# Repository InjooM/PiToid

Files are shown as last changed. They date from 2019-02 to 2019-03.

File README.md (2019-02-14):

# PiToid

## Intro
Small beginner's electronics project with Raspberry Pi Zero

This is a small project I started about mid-way through my first semester as a freshman at the University of Georgia. It is a Raspberry Pi in an Altoids Tin that acts as an emulator for video games through Retropie. In order to have a functioning "gameboy" I needed several components:

- A display
- An audio system
- A power management system
- Controls

## Display
For the display, I am using a 1.8" TFT display sold from Adafruit that came with a display driver. It uses SPI to communicate with the Raspberry Pi, so I designed a compact breakout board, referenced from the Adafruit breakout board, that fit my Altoids tin and used an FPC connector.

## Audio
For audio, I configured some of the GPIO pins of the RPi to output audio through PWM, ran it though a low-pass filter, then into an LM4810 audio amp with a 2-gang potentiometer acting as the feedback resistors for the amp. The output is a switching 3.5mm audio jack that runs into 2 8 Ohm speakers. This way I can plug in headphones as well.

## Power
For power management I am using a 3.7V Li-Poly battery sold by Adafruit, and I designed a battery charger and step-up, referenced from the Adafruit PowerBoost 1000 Charger. It also has load-sharing capabilites so when plugged in, the battery will only be charging.

## Controls
For controls I designed a breakout board for the Raspberry Pi and soldered tactile switches onto it, which are connected to the GPIO pins. The Pi is running Adafruit's Retrogame, which configures some GPIO pins as keyboard inputs.

## Final Words
The purpose of this project was not simply to build a DIY gameboy, although I do find gameboys to be fun. I mainly wanted to do this project because I wanted more hands-on experience designing and manufacturing PCB's, as well as putting my circuit analysis skills to the test. Reverse engineering the schematics from Adafruit and reading the datasheets for all the complicated components was difficult, however I believe it helped greatly in developing my electronics design skills. I plan on using these skills in the future for other applications, such as specific instrumentation design.

Most, if not all, of my boards are designed through EAGLE, and fabricated through OshPark. I ordered all my components from Digi-key or Mouser.

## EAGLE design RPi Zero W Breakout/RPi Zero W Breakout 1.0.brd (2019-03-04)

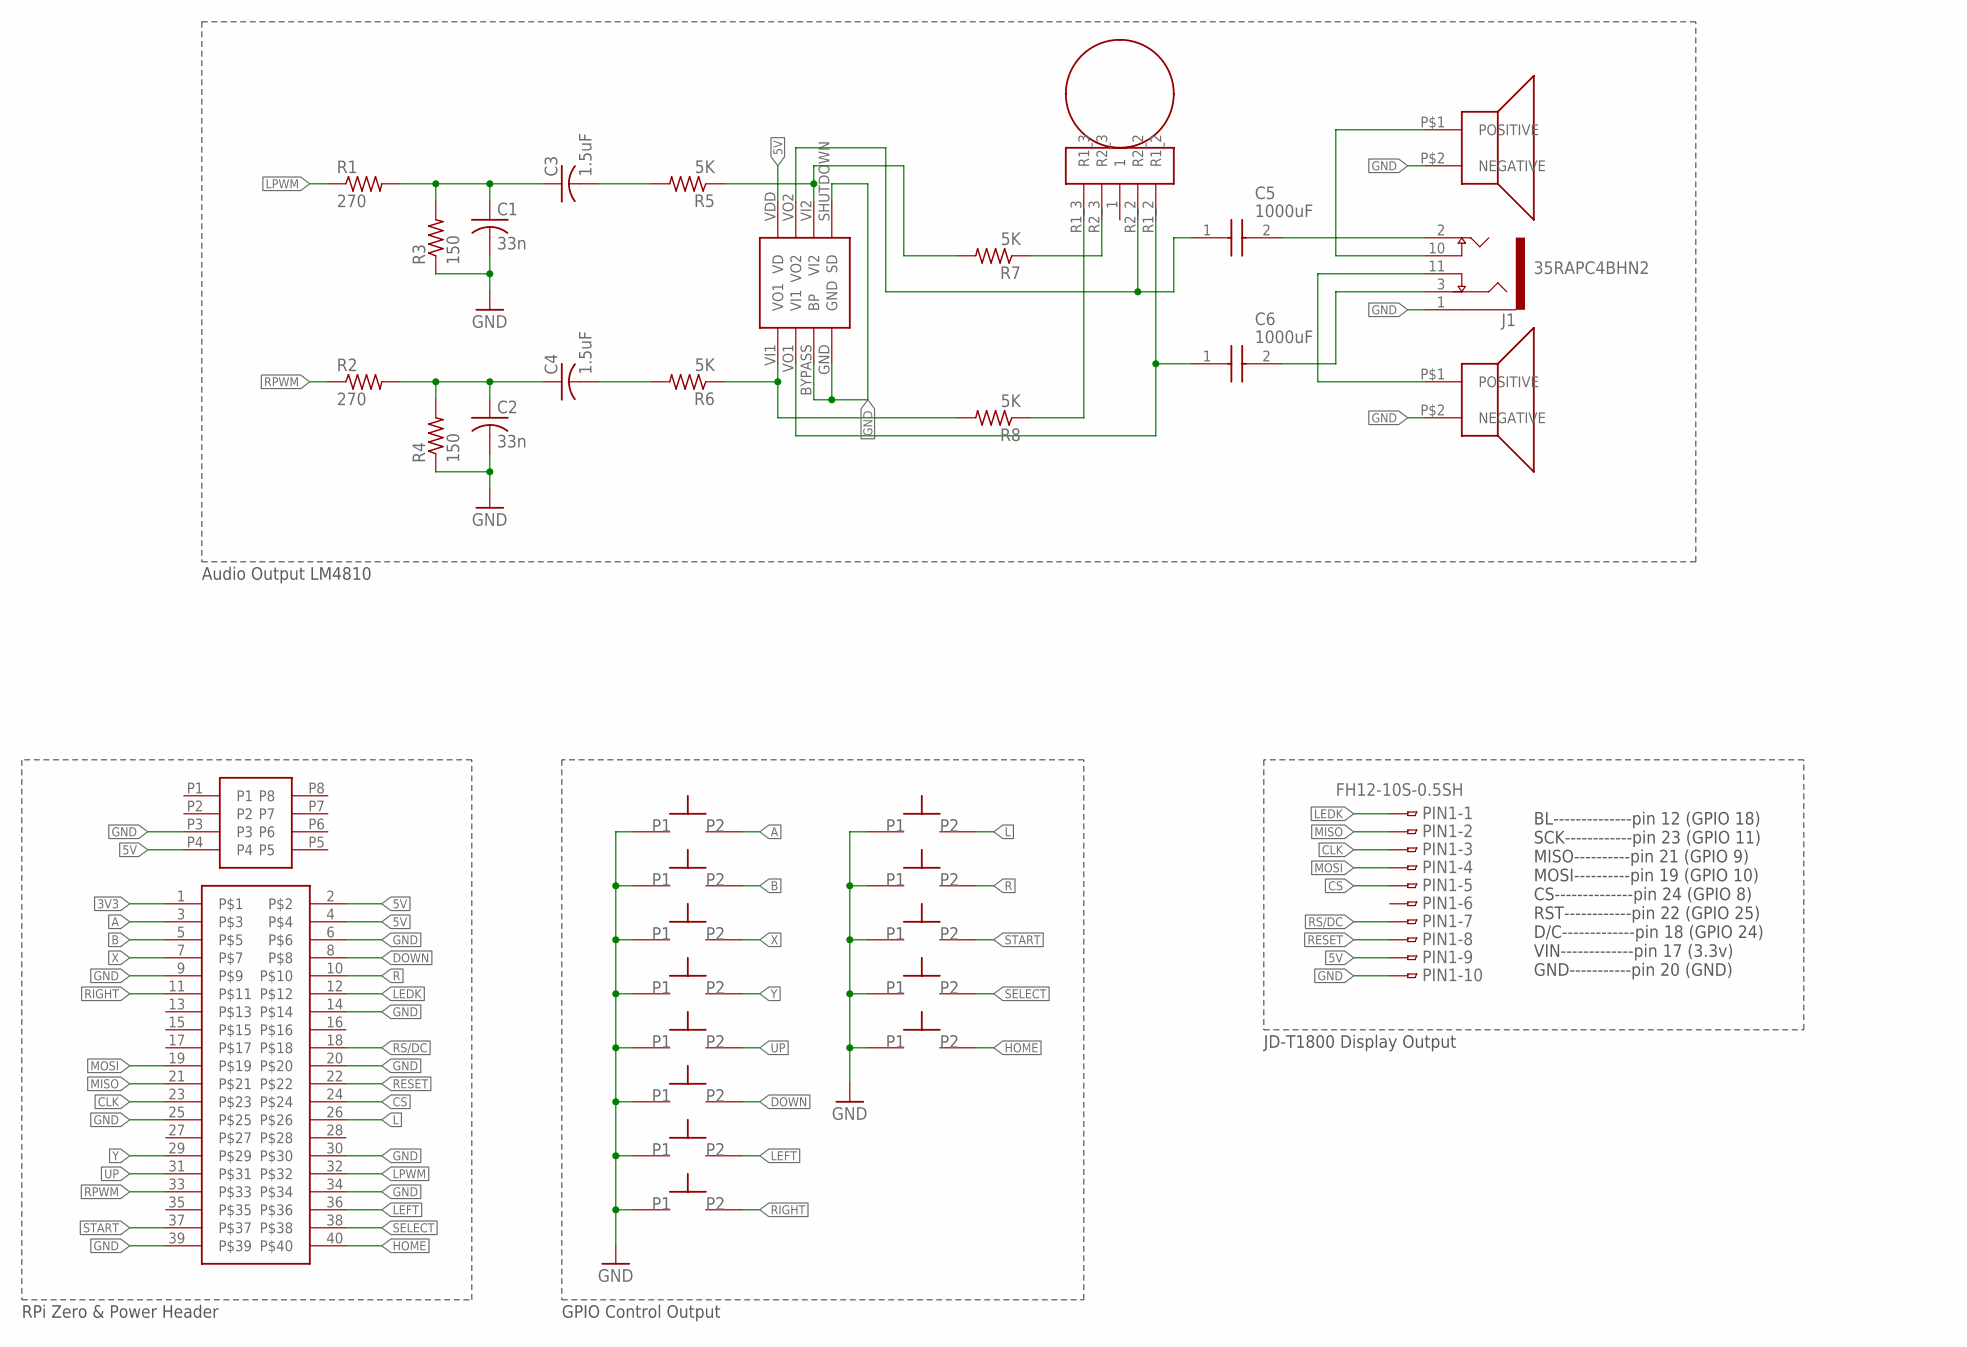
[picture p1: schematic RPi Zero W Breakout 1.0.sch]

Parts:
A: SPST_TACTILE_SWITCH; SPST_TACTILESWITCH_TL3301PF160QG
B: SPST_TACTILESWITCH_TL3301PF160QG
C1, C2: 33n; C0805K
C3, C4: 1.5uF; C0805K
C5, C6: 1000uF; UWT(8X10)
DOWN: SPST_TACTILESWITCH_TL3301PF160QG
HOME: SPST_TACTILESWITCH_TL3301PF160QG
J1: 35RAPC4BHN2; SWITCHCRAFT_35RAPC4BHN2
LEFT: SPST_TACTILESWITCH_TL3301PF160QG
LSPK: SP-1208
PIN1: FH12-10S-0.5SH
R1, R2: 270; R0805
R3, R4: 150; R0805
R5, R6, R7, R8: 5K; R0805
RF: RK14J12A0A0K
RIGHT: SPST_TACTILESWITCH_TL3301PF160QG
RSPK: SP-1208
SELECT: SPST_TACTILESWITCH_TL3301PF160QG
START: SPST_TACTILE_SWITCH; SPST_TACTILESWITCH_TL3301PF160QG
U$1: RPI_ZERO
U$2: LM4810MM/NOPBCT-ND; NOPBCT-ND
U$3: M22-6340442
U$4, U$5: SPST_TACTILE_SWITCHRIGHTANGLEBENT; SPST_TACTILESWITCH_TL3360CF185Q_BENTFRAME
UP: SPST_TACTILESWITCH_TL3301PF160QG
X: SPST_TACTILESWITCH_TL3301PF160QG
Y: SPST_TACTILESWITCH_TL3301PF160QG

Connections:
3V3: U$1.1
5V: PIN1.9, U$1.2, U$1.4, U$2.VDD (VD), U$3.P4
A: A.P$3, U$1.3
B: B.P$3, U$1.5
CLK: PIN1.3, U$1.23
CS: PIN1.5, U$1.24
DOWN: DOWN.P$3, U$1.8
GND: A.P$1, B.P$1, C1.2, C2.2, DOWN.P$1, HOME.P$1, J1.1, LEFT.P$1, LSPK.P$2 (NEGATIVE), PIN1.10, R3.1, R4.1, RIGHT.P$1, RSPK.P$2 (NEGATIVE), SELECT.P$1, START.P$1, U$1.6, U$1.9, U$1.14, U$1.20, U$1.25, U$1.30, U$1.34, U$1.39, U$2.BYPASS (BP), U$2.GND, U$2.SHUTDOWN (SD), U$3.P3, U$4.P$1, U$5.P$1, UP.P$1, X.P$1, Y.P$1
HOME: HOME.P$3, U$1.40
L: U$1.26, U$4.P$2
LEDK: PIN1.1, U$1.12
LEFT: LEFT.P$3, U$1.36
LPWM: R1.1, U$1.32
MISO: PIN1.2, U$1.21
MOSI: PIN1.4, U$1.19
unnamed: C1.1, C3.1, R1.2, R3.2
unnamed: C2.1, C4.1, R2.2, R4.2
unnamed: C3.2, R5.2
unnamed: R7.1, RF.R2_3
unnamed: C4.2, R6.2
unnamed: R8.1, RF.R1_3
unnamed: C6.1 (+), RF.R1_2, U$2.VO1 (VI1)
unnamed: C5.1 (+), RF.R2_2, U$2.VO2
unnamed: C5.2 (-), J1.2
unnamed: C6.2 (-), J1.3
unnamed: J1.10, LSPK.P$1 (POSITIVE)
unnamed: J1.11, RSPK.P$1 (POSITIVE)
unnamed: R5.1, R7.2, U$2.VI2
unnamed: R6.1, R8.2, U$2.VI1 (VO1)
R: U$1.10, U$5.P$2
RESET: PIN1.8, U$1.22
RIGHT: RIGHT.P$3, U$1.11
RPWM: R2.1, U$1.33
RS/DC: PIN1.7, U$1.18
SELECT: SELECT.P$3, U$1.38
START: START.P$3, U$1.37
UP: U$1.31, UP.P$3
X: U$1.7, X.P$3
Y: U$1.29, Y.P$3

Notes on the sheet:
BL--------------pin 12 (GPIO 18) SCK------------pin 23 (GPIO 11) MISO----------pin 21 (GPIO 9) MOSI----------pin 19 (GPIO 10) CS--------------pin 24 (GPIO 8) RST------------pin 22 (GPIO 25) D/C-------------pin 18 (GPIO 24) VIN-------------pin 17 (3.3v) GND-----------pin 20 (GND)
RPi Zero & Power Header
GPIO Control Output
JD-T1800 Display Output
Audio Output LM4810

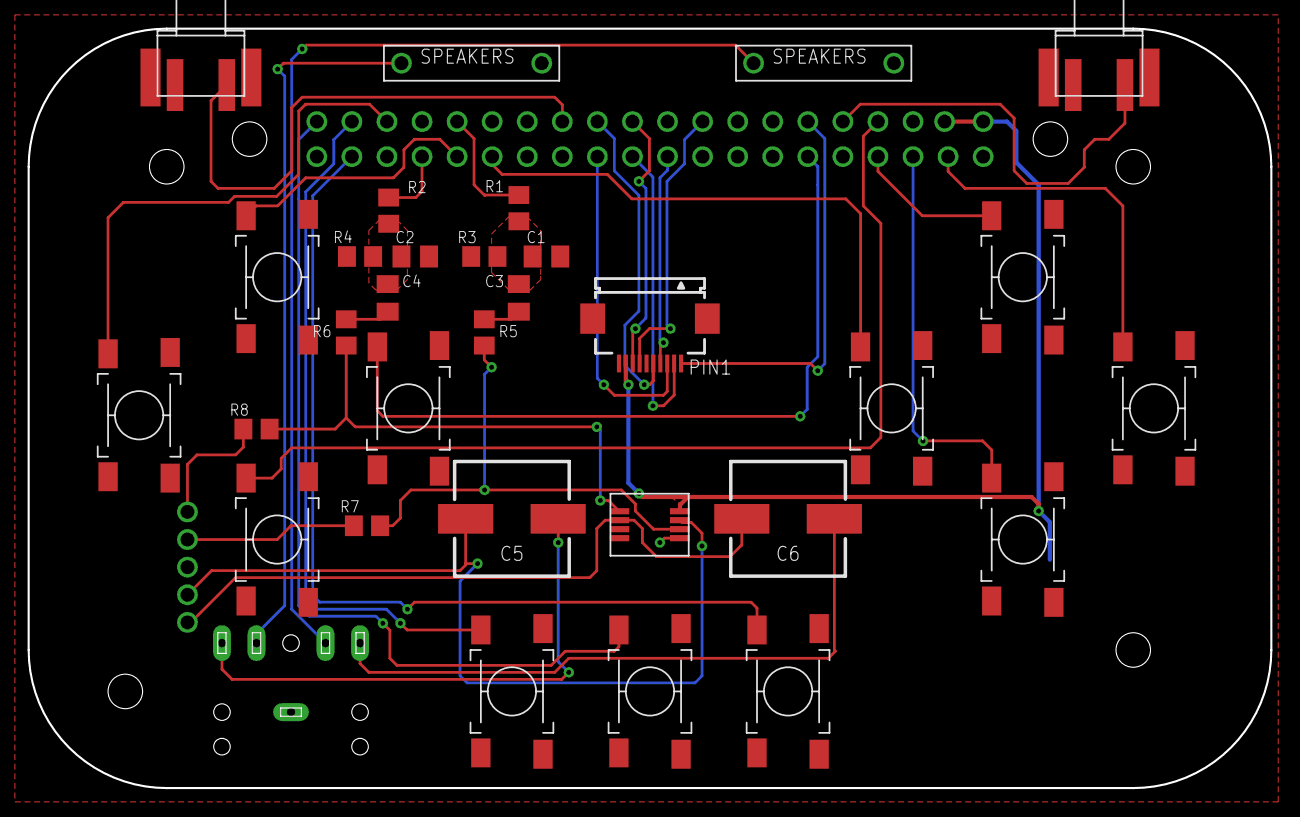
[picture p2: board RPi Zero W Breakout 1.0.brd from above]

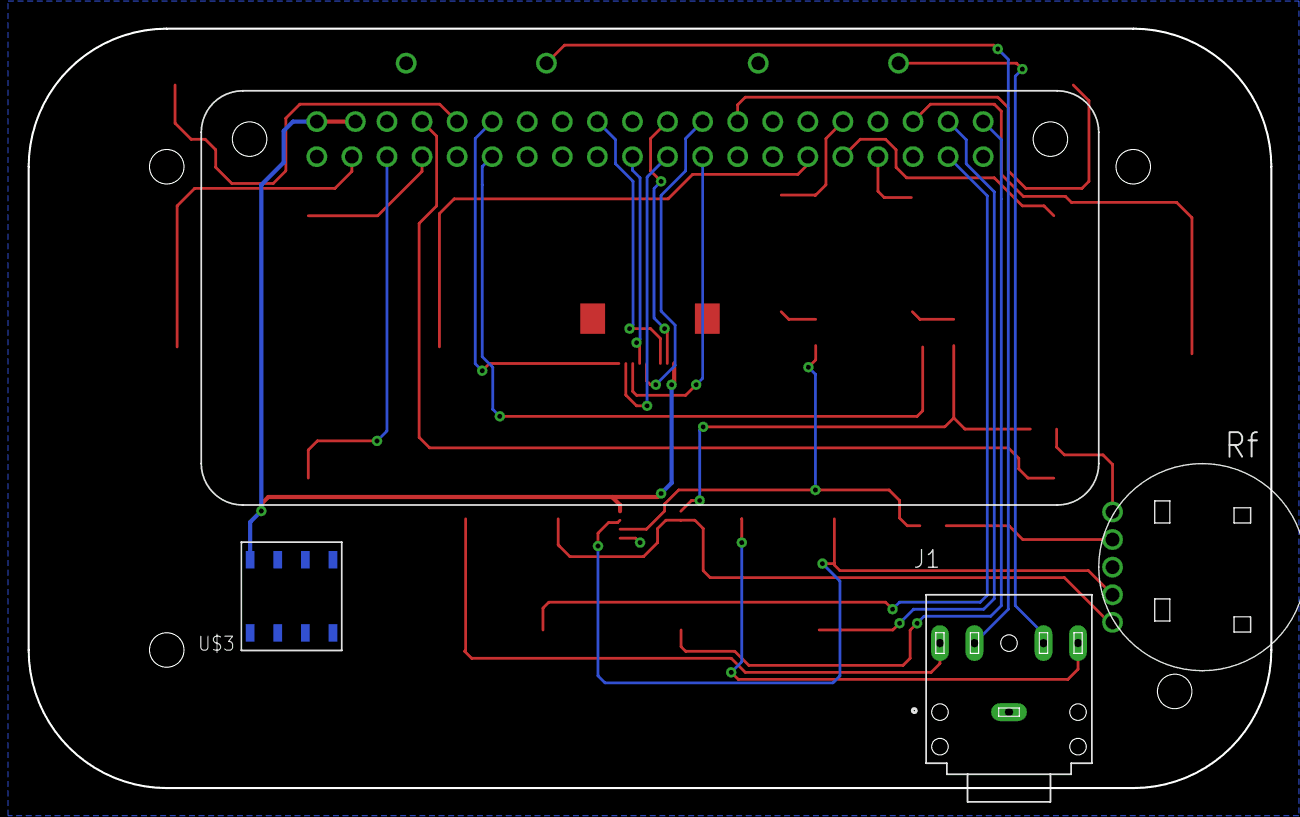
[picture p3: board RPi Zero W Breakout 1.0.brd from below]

Board: 2 copper layers, 90.0 x 55.0 mm, 35 parts (4 on the bottom side), 38 nets.

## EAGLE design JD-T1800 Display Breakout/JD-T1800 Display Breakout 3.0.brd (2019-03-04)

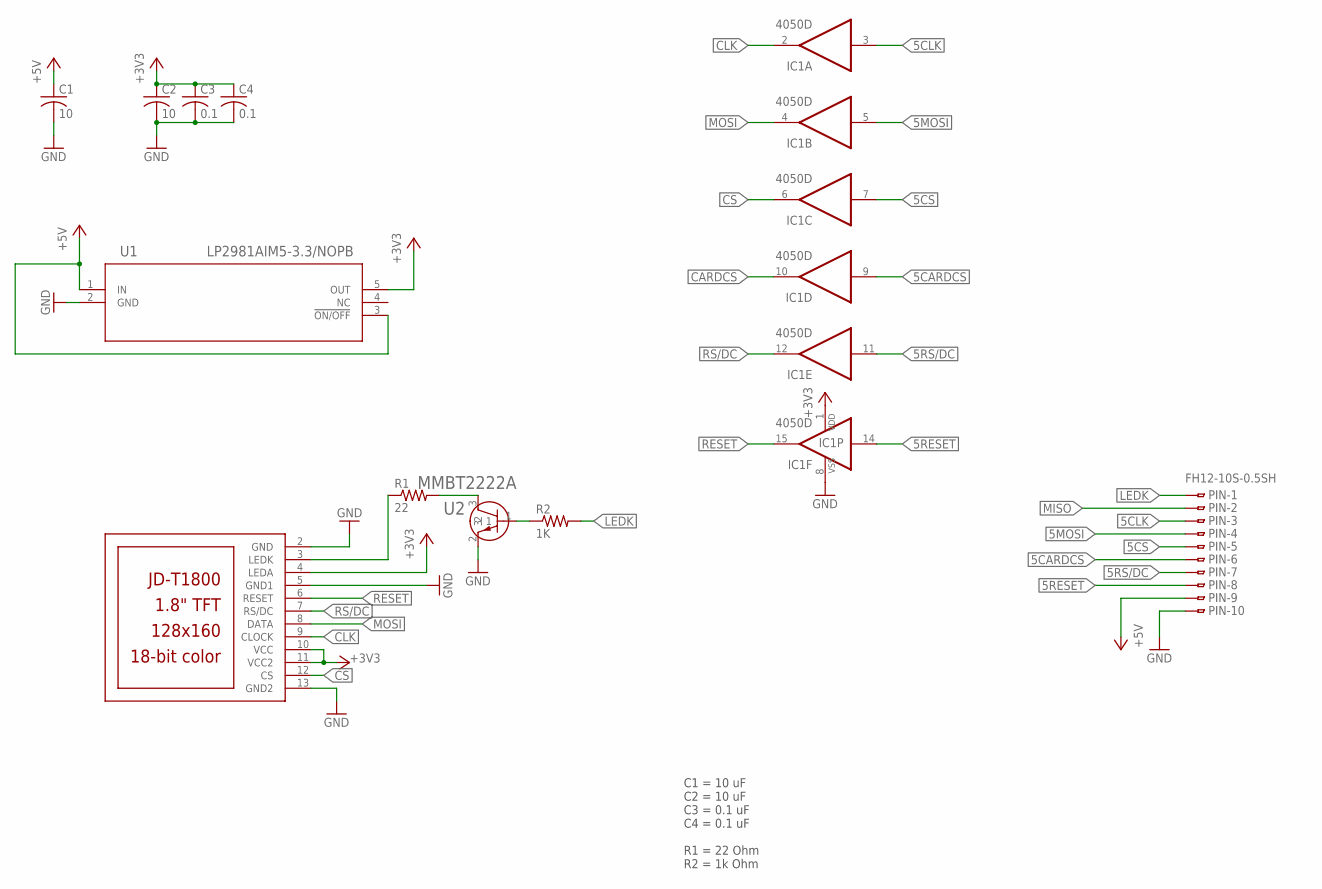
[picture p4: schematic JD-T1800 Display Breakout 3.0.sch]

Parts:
C1, C2: 10; C0805
C3, C4: 0.1; C0805
IC1: 4050D; SO16
PIN: FH12-10S-0.5SH
R1: 22; R0805
R2: 1K; R0805
U1: LP2981AIM5-3.3/NOPB; MF05A
U2: MMBT2222A; SOT23
U$1: JD-T1800

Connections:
5CARDCS: IC1.9 (I), PIN.6
5CLK: IC1.3 (I), PIN.3
5CS: IC1.7 (I), PIN.5
5MOSI: IC1.5 (I), PIN.4
5RESET: IC1.14 (I), PIN.8
5RS/DC: IC1.11 (I), PIN.7
+3V3: C2.1, C3.1, C4.1, IC1.1 (VDD), U1.5 (OUT), U$1.4 (LEDA), U$1.10 (VCC), U$1.11 (VCC2)
+5V: C1.1, PIN.9, U1.1 (IN), U1.3 (!ON/OFF)
CARDCS: IC1.10 (O)
CLK: IC1.2 (O), U$1.9 (CLOCK)
CS: IC1.6 (O), U$1.12 (CS)
GND: C1.2, C2.2, C3.2, C4.2, IC1.8 (VSS), PIN.10, U1.2 (GND), U2.2, U$1.2 (GND), U$1.5 (GND1), U$1.13 (GND2)
LEDK: PIN.1, R2.2
MISO: PIN.2
MOSI: IC1.4 (O), U$1.8 (DATA)
unnamed: R1.1, U$1.3 (LEDK)
unnamed: R1.2, U2.3
unnamed: R2.1, U2.1
RESET: IC1.15 (O), U$1.6 (RESET)
RS/DC: IC1.12 (O), U$1.7 (RS/DC)

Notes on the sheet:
C1 = 10 uF C2 = 10 uF C3 = 0.1 uF C4 = 0.1 uF R1 = 22 Ohm R2 = 1k Ohm

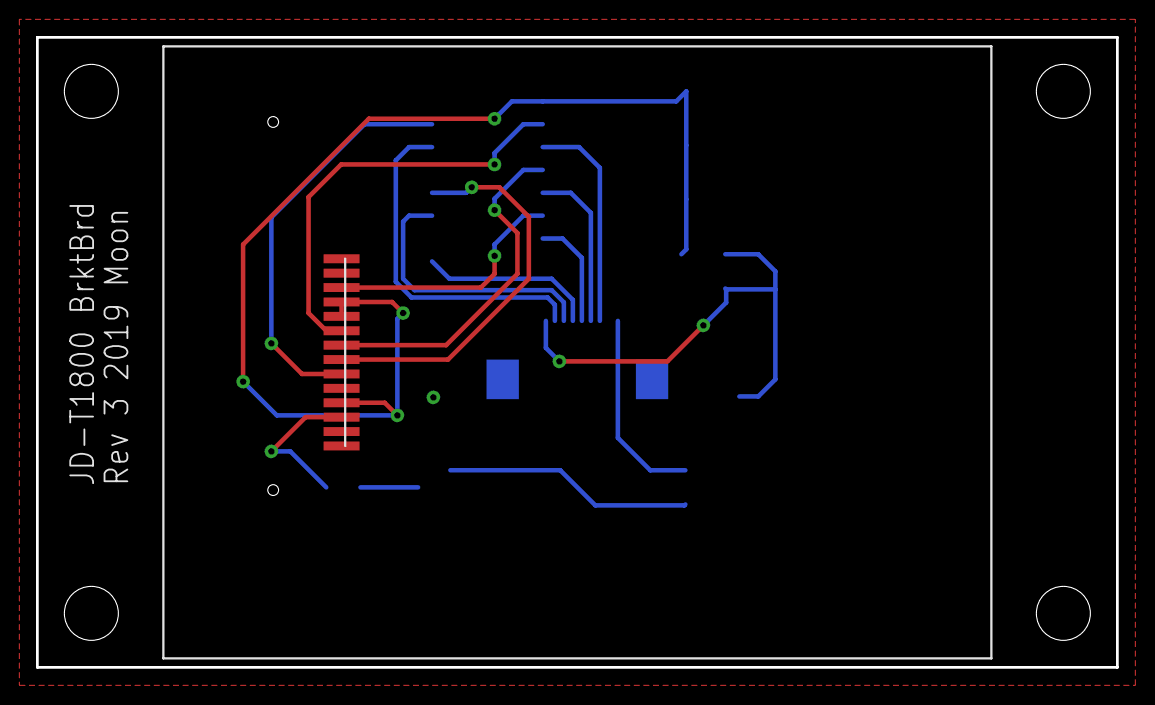
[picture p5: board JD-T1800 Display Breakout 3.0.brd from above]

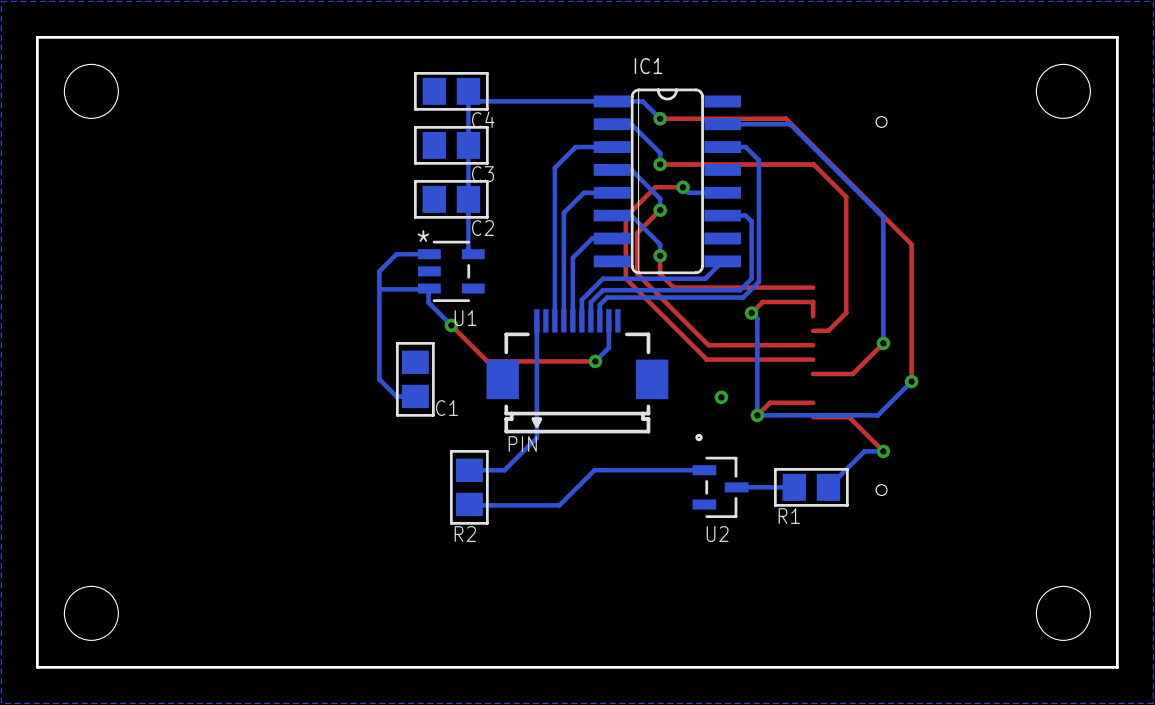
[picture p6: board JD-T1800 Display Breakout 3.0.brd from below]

Board: 2 copper layers, 60.0 x 35.0 mm, 11 parts (10 on the bottom side), 18 nets.

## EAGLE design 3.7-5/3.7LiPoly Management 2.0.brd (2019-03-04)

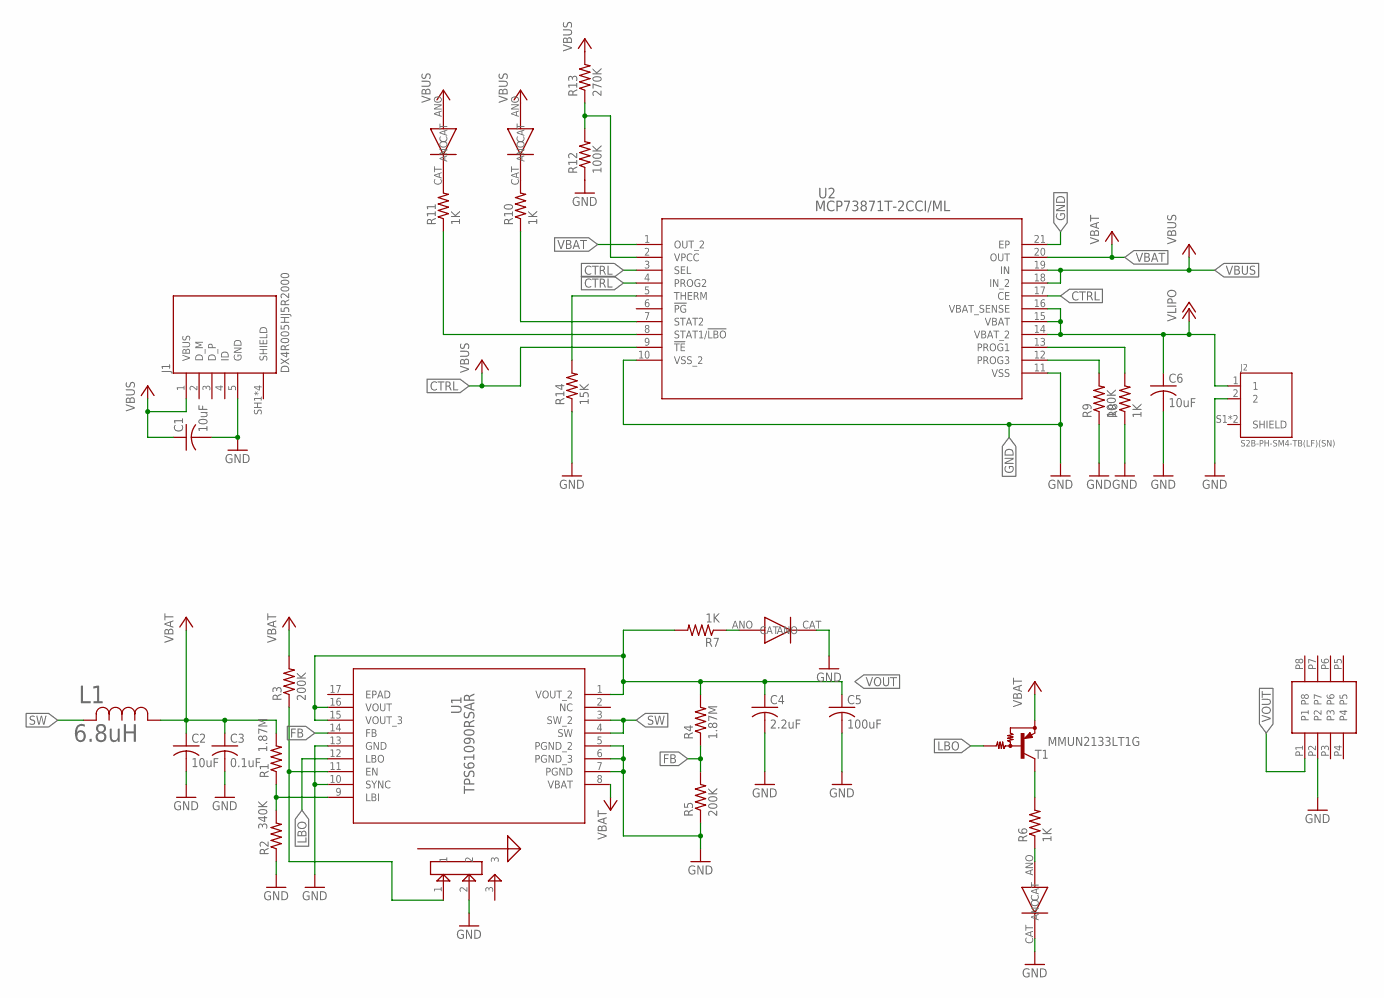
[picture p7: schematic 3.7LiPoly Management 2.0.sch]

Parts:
C1, C2, C6: 10uF; C0805
C3: 0.1uF; C0805
C4: 2.2uF; C0805
C5: 100uF; C0805
CHARGE: YELLOW; WP934AD
DONE: GREEN; WP934AD
H1: M22-6340442
J1: DX4R005HJ5R2000; JAE_DX4R005HJ5R2000
J2: S2B-PH-SM4-TB(LF)(SN); JST_S2B-PH-SM4-TB(LF)(SN)
L1: 6.8uH; IND_5028
LBO: RED; WP934AD
POWERON: BLUE; WP934EW
R1, R4: 1.87M; R0805
R2: 340K; R0805
R3, R5: 200K; R0805
R6, R7, R8, R10, R11: 1K; R0805
R9, R12: 100K; R0805
R13: 270K; R0805
R14: 15K; R0805
T1: MMUN2133LT1G; SC59-BEC
U1: TPS61090RSAR; RSA16_2P7X2P7
U2: MCP73871T-2CCI/ML; QFN20_4X4MC
U$2: JS102011SAQN

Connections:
+3V3: CHARGE.ANO, DONE.ANO, R13.2
CTRL: U2.3 (SEL), U2.4 (PROG2), U2.9 (!TE), U2.17 (CE)
FB: R4.1, R5.2, U1.14 (FB)
GND: C1.2, C2.2, C3.2, C4.2, C5.2, C6.2, H1.P2, J1.5 (GND), J2.2, LBO.CAT, POWERON.CAT, R2.1, R5.1, R8.1, R9.1, R12.1, R14.1, U1.5 (PGND_2), U1.6 (PGND_3), U1.7 (PGND), U1.10 (SYNC), U1.13 (GND), U2.10 (VSS_2), U2.11 (VSS), U2.21 (EP), U$2.2
LBO: T1.B, U1.12 (LBO)
unnamed: R1.1, R2.2, U1.9 (LBI)
unnamed: R3.1, U1.11 (EN), U$2.1
unnamed: CHARGE.CAT, R11.2
unnamed: R8.2, U2.13 (PROG1)
unnamed: R6.2, T1.C
unnamed: LBO.ANO, R6.1
unnamed: POWERON.ANO, R7.1
unnamed: R9.2, U2.12 (PROG3)
unnamed: DONE.CAT, R10.2
unnamed: R11.1, U2.8 (STAT1/!LBO)
unnamed: R10.1, U2.7 (STAT2)
unnamed: R14.2, U2.5 (THERM)
unnamed: R12.2, R13.1, U2.2 (VPCC)
SW: L1.2, U1.3 (SW_2), U1.4 (SW)
VBAT: C2.1, C3.1, L1.1, R1.2, R3.2, T1.E, U1.8 (VBAT), U2.1 (OUT_2), U2.20 (OUT)
VBUS: C1.1, J1.1 (VBUS), U2.18 (IN_2), U2.19 (IN)
VLIPO: C6.1, J2.1, U2.14 (VBAT_2), U2.15 (VBAT), U2.16 (VBAT_SENSE)
VOUT: C4.1, C5.1, H1.P1, R4.2, R7.2, U1.1 (VOUT_2), U1.15 (VOUT_3), U1.16 (VOUT)

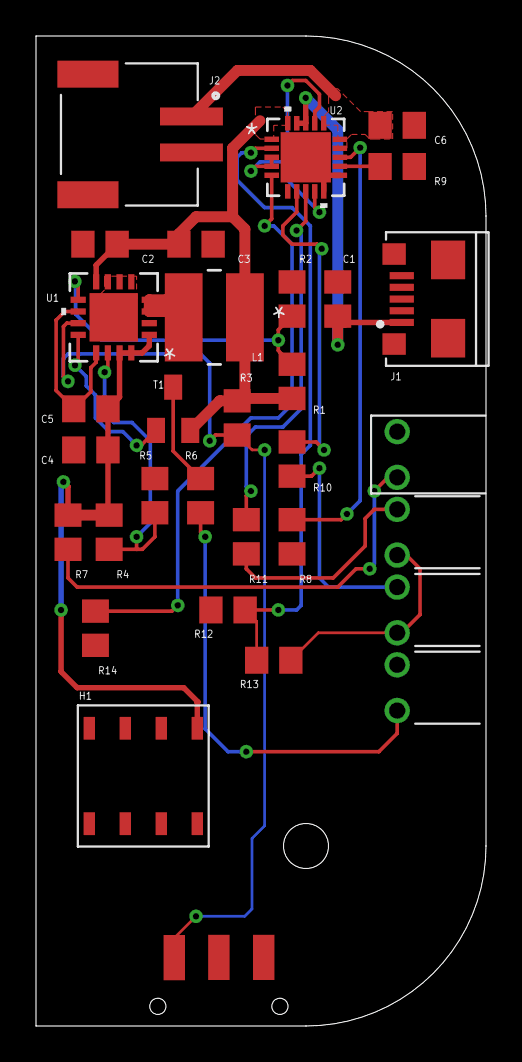
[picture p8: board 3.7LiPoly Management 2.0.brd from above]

Board: 2 copper layers, 25.0 x 55.0 mm, 32 parts (0 on the bottom side), 23 nets.

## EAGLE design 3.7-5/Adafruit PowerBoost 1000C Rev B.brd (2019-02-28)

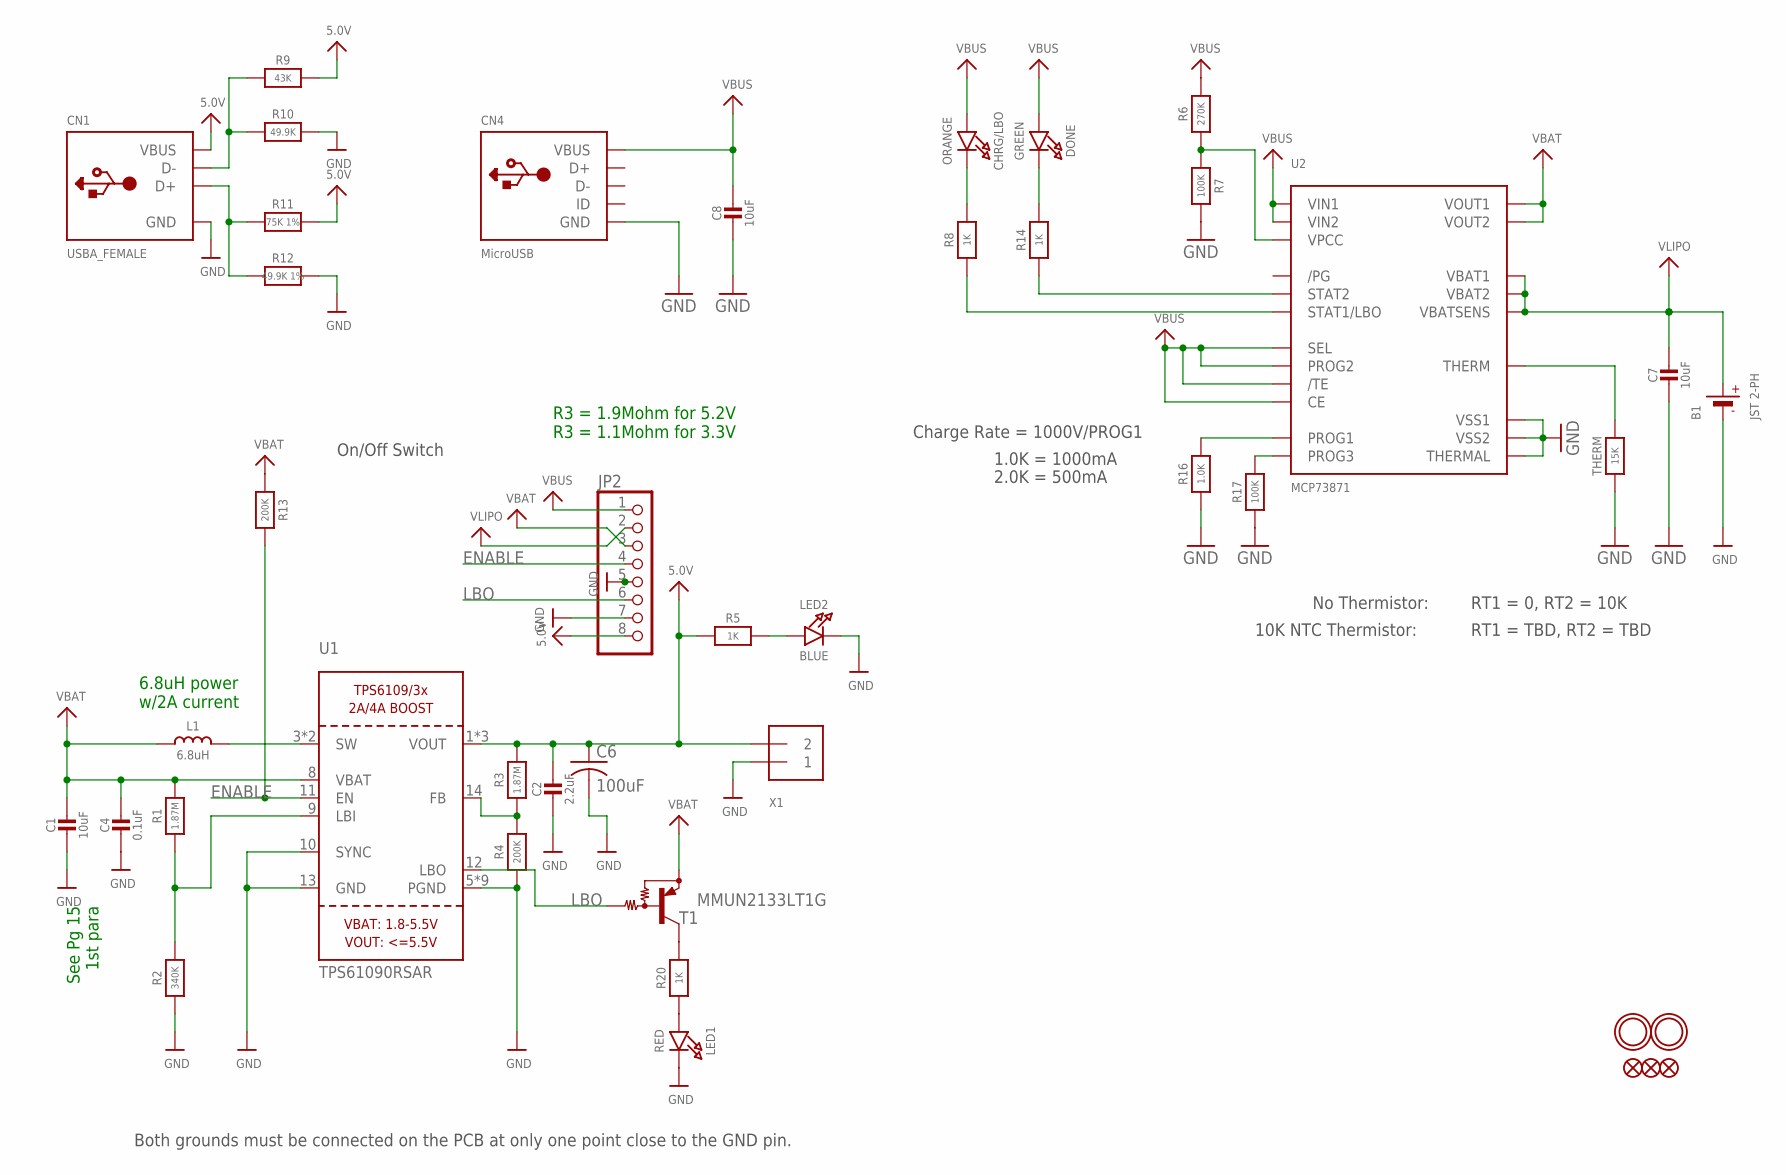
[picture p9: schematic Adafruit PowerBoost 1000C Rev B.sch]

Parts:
B1: JST 2-PH; JSTPH2
C1, C7, C8: 10uF; 0805-NO
C2: 2.2uF; 0805-NO
C4: 0.1uF; 0805_10MGAP
C6: 100uF; C1210
CHRG/LBO: ORANGE; CHIPLED_0805_NOOUTLINE
CN1: USBA_FEMALE; USB_HOST-PTH
CN4: MicroUSB; 4UCONN_20329
DONE: GREEN; CHIPLED_0805_NOOUTLINE
FID1, FID2, FID3: FIDUCIAL""; FIDUCIAL_1MM
JP2: HEADER-1X8ROUND; 1X08_ROUND
L1: 6.8uH; INDUCTOR_5X5MM_TDK_VLC5045
LED1: RED; CHIPLED_0805_NOOUTLINE
LED2: BLUE; CHIPLED_0805_NOOUTLINE
R1: 1.87M; _0805MP
R2: 340K; _0805MP
R3: 1.87M; 0805-NO
R4, R13: 200K; 0805-NO
R5, R8, R14, R20: 1K; 0805-NO
R6: 270K; 0805-NO
R7, R17: 100K; 0805-NO
R9: 43K; 0805-NO
R10: 49.9K; 0805-NO
R11: 75K 1%; 0805-NO
R12: 49.9K 1%; 0805-NO
R16: 1.0K; 0805-NO
T1: MMUN2133LT1G; SC59-BEC
THERM: 15K; 0805-NO
U1: TPS61090RSAR; PVQFN-16
U2: MCP73871; QFN20_4MM
U$10, U$11: MOUNTINGHOLE2.5; MOUNTINGHOLE_2.5_PLATED
X1: TERMBLOCK_1X2; TERMBLOCK_1X2-3.5MM

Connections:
5.0V: C2.1, C6.1, CN1.VBUS, JP2.8, R3.2, R5.1, R9.2, R11.2, U1.1 (VOUT), U1.15 (VOUT), U1.16 (VOUT), X1.2
D+: CN1.D+, R11.1, R12.1
D-: CN1.D-, R9.1, R10.1
ENABLE: JP2.4, R13.2, U1.11 (EN)
GND: B1.1 (-), C1.2, C2.2, C4.2, C6.2, C7.2, C8.2, CN1.GND, CN4.BASE@1 (GND), CN4.BASE@2 (GND), CN4.GND, CN4.SPRT@1 (GND), CN4.SPRT@2 (GND), CN4.SPRT@3 (GND), CN4.SPRT@4 (GND), JP2.5, JP2.7, LED1.C, LED2.C, R2.1, R4.1, R7.2, R10.2, R12.2, R16.1, R17.1, THERM.1, U1.5 (PGND), U1.6 (PGND), U1.7 (PGND), U1.10 (SYNC), U1.13 (GND), U1.P$18 (PGND), U1.P$19 (PGND), U1.P$20 (PGND), U1.P$21 (PGND), U1.P$22 (PGND), U1.THERMAL (PGND), U2.P$10 (VSS1), U2.P$11 (VSS2), U2.P$21 (THERMAL), X1.1
LBO: JP2.6, T1.B, U1.12 (LBO)
unnamed: L1.P$2 (2), U1.3 (SW), U1.4 (SW)
unnamed: LED1.A, R20.1
unnamed: R1.1, R2.2, U1.9 (LBI)
unnamed: LED2.A, R5.2
unnamed: R3.1, R4.2, U1.14 (FB)
unnamed: R20.2, T1.C
unnamed: R6.1, R7.1, U2.P$2 (VPCC)
unnamed: DONE.C, R14.2
unnamed: R14.1, U2.P$7 (STAT2)
unnamed: THERM.2, U2.P$5 (THERM)
unnamed: R8.1, U2.P$8 (STAT1/LBO)
unnamed: CHRG/LBO.C, R8.2
unnamed: R17.2, U2.P$12 (PROG3)
unnamed: R16.2, U2.P$13 (PROG1)
VBAT: C1.1, C4.1, JP2.3, L1.P$1 (1), R1.2, R13.1, T1.E, U1.8 (VBAT), U2.P$1 (VOUT1), U2.P$20 (VOUT2)
VBUS: C8.1, CHRG/LBO.A, CN4.VBUS, DONE.A, JP2.1, R6.2, U2.P$3 (SEL), U2.P$4 (PROG2), U2.P$9 (/TE), U2.P$17 (CE), U2.P$18 (VIN1), U2.P$19 (VIN2)
VLIPO: B1.2 (+), C7.1, JP2.2, U2.P$14 (VBAT1), U2.P$15 (VBAT2), U2.P$16 (VBATSENS)

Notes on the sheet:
Both grounds must be connected on the PCB at only one point close to the GND pin.
On/Off Switch
See Pg 15 1st para
6.8uH power w/2A current
R3 = 1.9Mohm for 5.2V R3 = 1.1Mohm for 3.3V
Charge Rate = 1000V/PROG1
1.0K = 1000mA
2.0K = 500mA
No Thermistor:
10K NTC Thermistor:
RT1 = 0, RT2 = 10K
RT1 = TBD, RT2 = TBD



Board: 2 copper layers, 36.1 x 22.9 mm, 47 parts (2 on the bottom side), 23 nets.

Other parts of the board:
U$12: PCBFEAT-REV-040
U$25: SYMBOL_PLUS
U$26: SYMBOL_MINUS
U$28: ADAFRUIT_5MM
U$45: ADAFRUIT_3.5MM

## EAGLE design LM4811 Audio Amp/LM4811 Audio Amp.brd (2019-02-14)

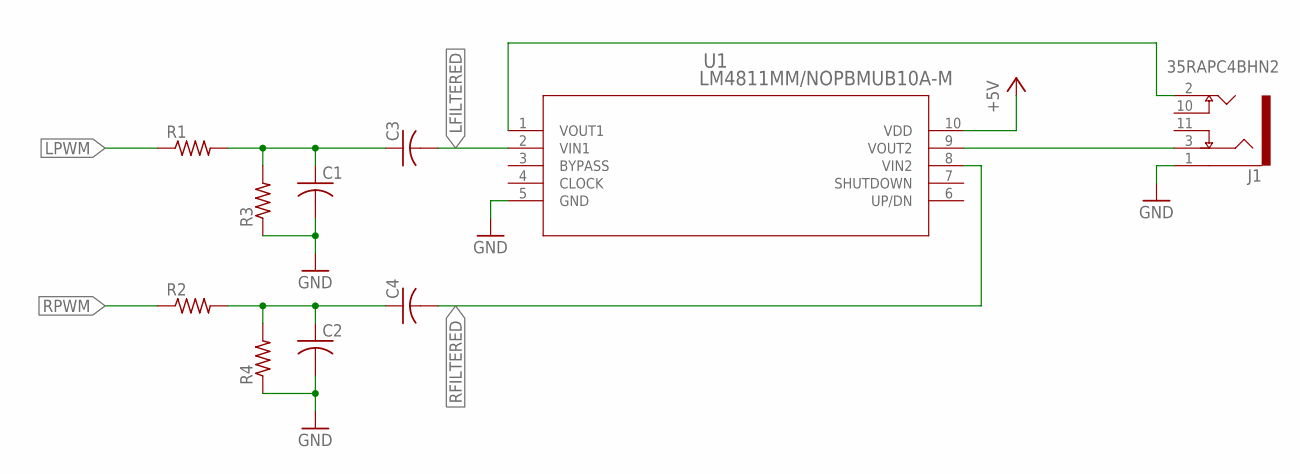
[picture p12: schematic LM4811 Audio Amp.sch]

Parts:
C1, C2, C3, C4: C-USC0805K; C0805K
J1: 35RAPC4BHN2; SWITCHCRAFT_35RAPC4BHN2
R1, R2, R3, R4: R-US_R0805; R0805
U1: LM4811MM/NOPBMUB10A-M; MUB10A-M

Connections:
+5V: U1.10 (VDD)
GND: C1.2, C2.2, J1.1, R3.1, R4.1, U1.5 (GND)
LFILTERED: C3.2, U1.2 (VIN1)
LPWM: R1.1
unnamed: C1.1, C3.1, R1.2, R3.2
unnamed: C2.1, C4.1, R2.2, R4.2
unnamed: J1.2, U1.1 (VOUT1)
unnamed: J1.3, U1.9 (VOUT2)
RFILTERED: C4.2, U1.8 (VIN2)
RPWM: R2.1

Board: 2 copper layers, 10 parts (0 on the bottom side), 7 nets, no tracks yet.

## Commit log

2019-02-14 Add files via upload
    Uploading boards/schem that I've been working on. Some of these are not the 1st revisions.
    [3.7LiPoly Management.brd, 3.7LiPoly Management.sch, JD-T1800 Display Breakout.brd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]
2019-02-28 Update
    Getting more familiar with Git and updating cleanly
    [3.7LiPoly Management.brd, 3.7LiPoly Management.sch, 3.7LiPoly Management_1.0.brd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]
2019-02-28 Reorganizing
    Reorganizing folders
    [Adafruit PowerBoost 1000C Rev B.brd, Adafruit PowerBoost 1000C Rev B.sch, DRILEGEND.CFG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]
2019-02-28 Rename
    Renamed files to correct versions
    [3.7LiPoly Management 1.0.brd, 3.7LiPoly Management 2.0.brd, 3.7LiPoly Management 2.0.sch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]
2019-03-01 RPi Zero W Breakout Rev 0.3
    Cleaned up schematic symbols and finalized schematic.
    [3.7LiPoly Management.brd, RPi Zero W Breakout 0.2.brd, RPi Zero W Breakout 0.2.sch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]
2019-03-04 Update
    Finished RPi Zero Breakout Schem and board layout. Need to route. Moved LiPoly Management's power headers so it aligned with RPi Breakout's. Still need to find perfect tactile buttons for RPi Breakou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
2019-03-04 RPi Zero Complete
    Finished routing RPi Zero, ERC and DRC came out okay.
    [RPi Zero W Breakout 1.0.brd, RPi Zero W Breakout 1.0.sch]

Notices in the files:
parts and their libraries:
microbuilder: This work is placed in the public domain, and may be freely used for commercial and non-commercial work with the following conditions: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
